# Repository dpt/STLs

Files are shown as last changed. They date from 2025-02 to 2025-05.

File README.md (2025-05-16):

OpenSCAD/STL Acorn Risc PC Components
=====================================

This repository contains OpenSCAD sources and generated STL models of the Acorn Risc PC power button and case locking pins.

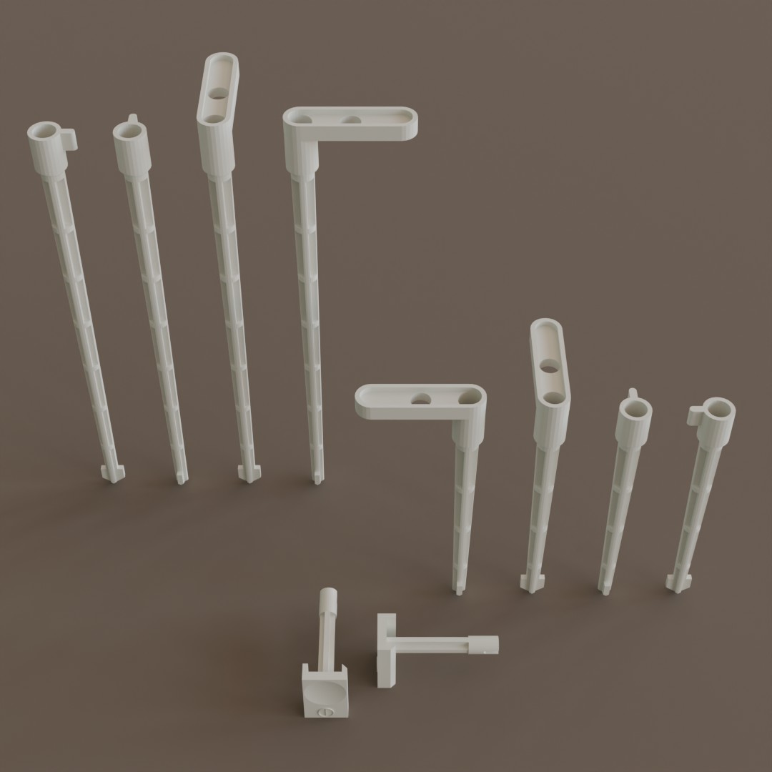
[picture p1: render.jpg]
Models


The OpenSCAD sources are provided. They're parameterised in numerous ways so you can tweak the models. e.g. you can increase the level of detail, or change the models in ways to make them amenable to your 3D printing preferences.

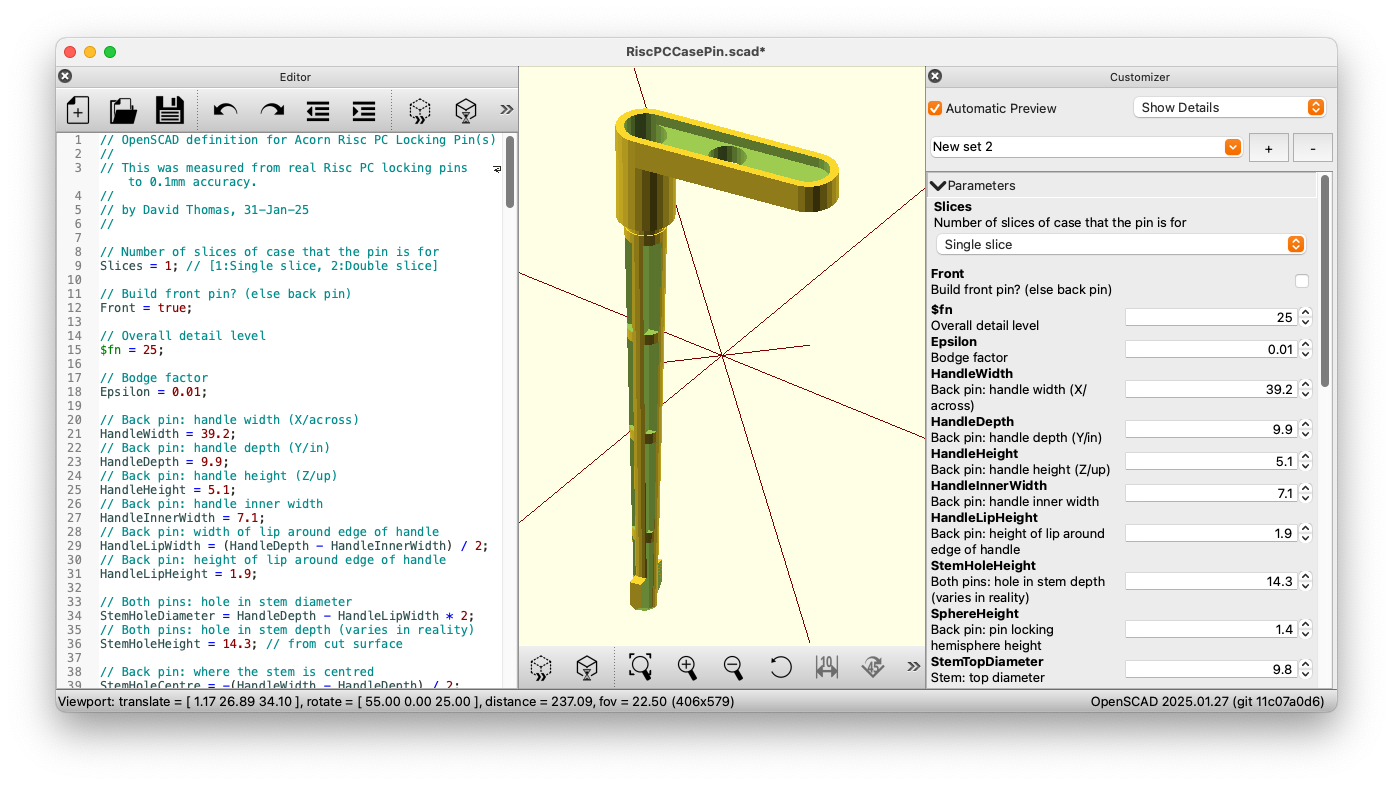
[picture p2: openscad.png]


Notes
-----
1. The parts were measured and recreated to an accuracy of 0.1mm but I can't offer any guarantees other than that.
2. The originals are injection moulded and these models are a recreation of those parts. If you 3D print these models you may need to adjust these models for your chosen method (e.g. thickening or filling in parts).
3. While you can make three slice or larger case pins note that Acorn used very sturdy metal pins in those cases.

Related Models
--------------
RiscPC Spring Insert by Nic756655 <https://www.thingiverse.com/thing:6777776>  
RiscPC Pegs 1 Slice by Nic756655 <https://www.thingiverse.com/thing:6776757>  
Archimedes & RiscPC Half-Width Podule Slot Covers by distantcamera <https://www.thingiverse.com/thing:5325053>  
Acorn RiscPC Power Switch by mcnewton <https://www.thingiverse.com/thing:2854144>

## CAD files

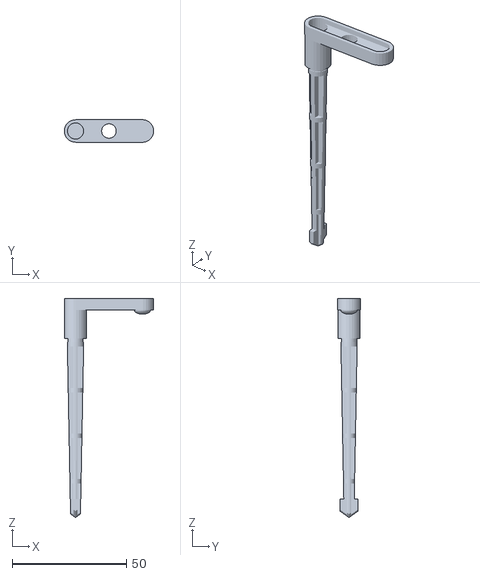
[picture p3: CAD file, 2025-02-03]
RiscPCCasePins/RiscPCCaseBackPin1L.stl
39.2 x 9.88 x 95.9

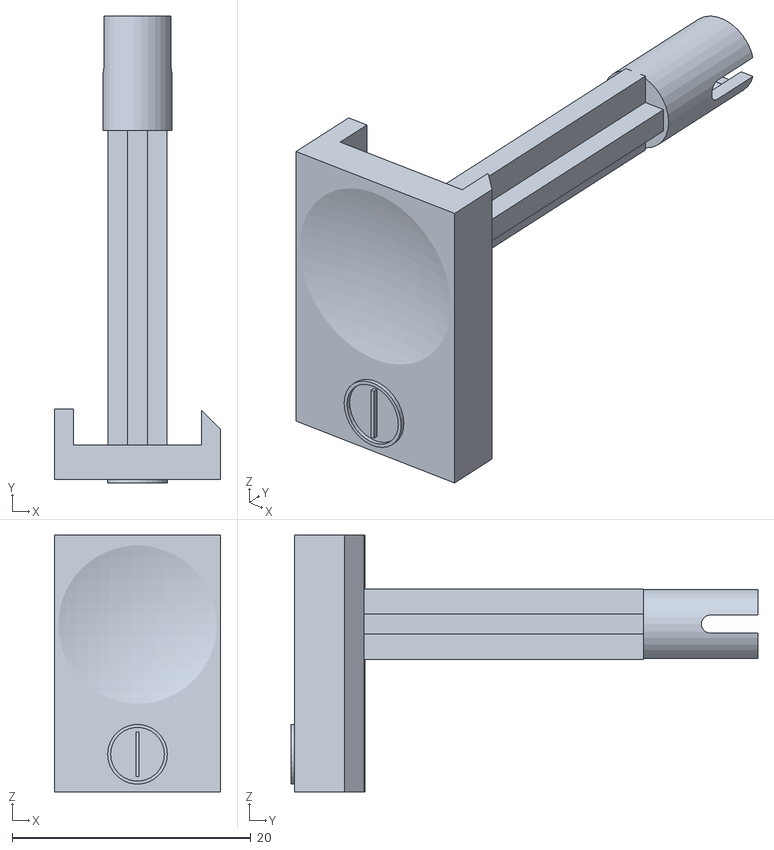
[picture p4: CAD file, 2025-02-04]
RiscPCPowerButton/RiscPCPowerButton.stl
13.9 x 39.1 x 21.5

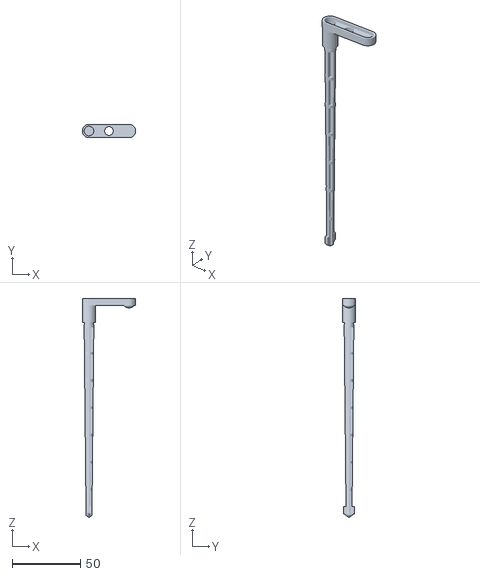
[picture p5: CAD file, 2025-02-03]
RiscPCCasePins/RiscPCCaseBackPin2L.stl
39.2 x 9.88 x 160.6

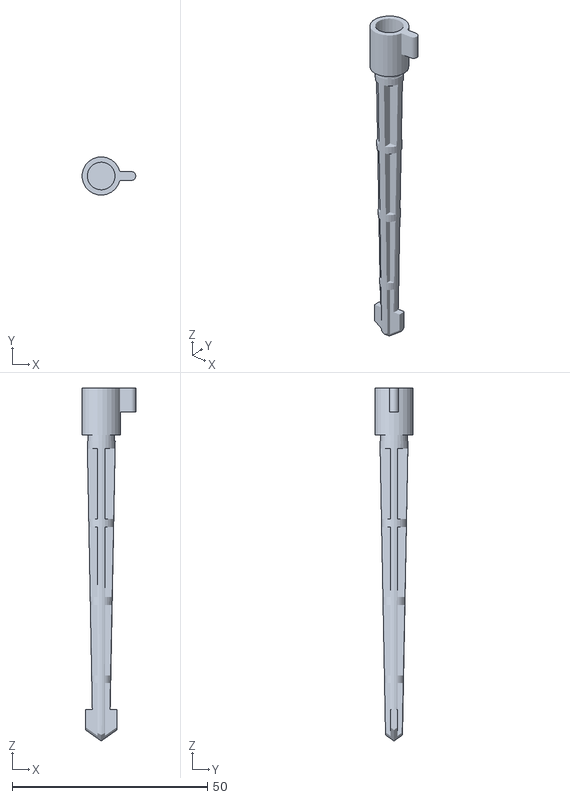
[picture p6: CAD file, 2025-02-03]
RiscPCCasePins/RiscPCCaseFrontPin1L.stl
13.7 x 9.78 x 90.3

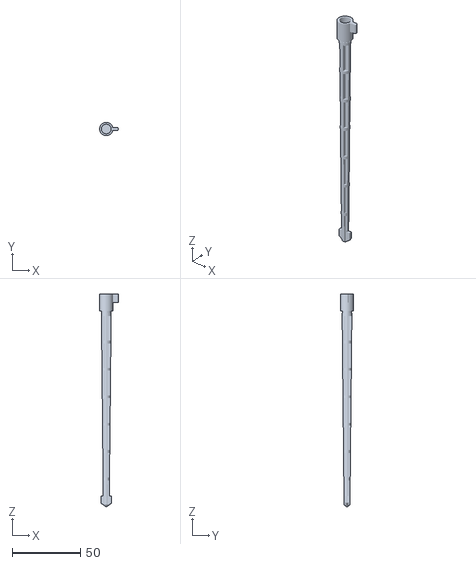
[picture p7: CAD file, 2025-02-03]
RiscPCCasePins/RiscPCCaseFrontPin2L.stl
13.7 x 9.78 x 155.5

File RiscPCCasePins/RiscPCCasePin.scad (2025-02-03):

// OpenSCAD definition for Acorn Risc PC Locking Pin(s)
//
// This was measured from real Risc PC locking pins to 0.1mm accuracy.
//
// by David Thomas, 31-Jan-25
//

// Number of slices of case that the pin is for
Slices = 1; // [1:Single slice, 2:Double slice]

// Build front pin? (else back pin)
Front = true;

// Overall detail level
$fn = 25;

// Bodge factor
Epsilon = 0.01;

// Back pin: handle width (X/across)
HandleWidth = 39.2;
// Back pin: handle depth (Y/in)
HandleDepth = 9.9;
// Back pin: handle height (Z/up)
HandleHeight = 5.1;
// Back pin: handle inner width
HandleInnerWidth = 7.1;
// Back pin: width of lip around edge of handle
HandleLipWidth = (HandleDepth - HandleInnerWidth) / 2;
// Back pin: height of lip around edge of handle
HandleLipHeight = 1.9;

// Both pins: hole in stem diameter
StemHoleDiameter = HandleDepth - HandleLipWidth * 2;
// Both pins: hole in stem depth (varies in reality)
StemHoleHeight = 14.3; // from cut surface

// Back pin: where the stem is centred
StemHoleCentre = -(HandleWidth - HandleDepth) / 2;

// Back pin: padlock hole diameter
LockHoleDiameter = HandleInnerWidth - 0.7;
// Back pin: padlock hole height
LockHoleHeight = HandleHeight + Epsilon;

// Back pin: pin locking hemisphere diameter
SphereDiameter = HandleDepth - HandleLipWidth * 2;
// Back pin: pin locking hemisphere height
SphereHeight = 1.4;

// Stem: top diameter
StemTopDiameter = 9.8;
// Stem: top depth (front single slicer is 1/2mm shorter)
StemTopHeight = (Front && Slices == 1) ? 12 : 12.5;

// Stem: O-ring inset diameter
StemORingInsetDiameter = 6.8;
// Stem: O-ring inset height
StemORingInsetHeight = 1.5;
// Stem: show the O-ring
ShowORing = false;

// Stem: fixed size portion of height
StemFixedHeight = 12.1;
// Stem: per-slice height (depth of a case slice)
StemPerSliceHeight = 64.7; // measured
// Stem: overall height (note rubber ring inset height not part of this)
StemHeight = StemFixedHeight + StemPerSliceHeight * Slices;
// Stem: diameter at top
StemUpperDiameter = 7.2;
// Stem: diameter at bottom
StemBottomDiameter = 4.3;

// Stem: cutout width/depth
StemCutoutSize = 4;
// Stem: cutout height (doesn't vary with number of slices)
StemCutoutHeight = 18;
// Stem: cutout interval
StemCutoutInterval = 20;
// Stem: increase for shallower cuts
StemCutoutOffset = 1.9;

// Barb: width
BarbWidth = 8;
// Barb: depth
BarbDepth = StemCutoutOffset;
// Barb: height
BarbHeight = 8.1;

// Front pin: width of handle (extends halfway into lip but note lip width comes from Back pin calc)
FrontHandleWidth = 14.9 - StemTopDiameter + HandleLipWidth / 2 - 2.3;
// Front pin: increase this for a chunkier handle
FrontHandleDepth = 2.3;
// Front pin: increase this for a deeper handle
FrontHandleHeight = 6.1;

module capsule(width, radius) {
	hull() {
		x = width / 2 - radius;
		translate([-x, 0, 0]) circle(r = radius);
		translate([+x, 0, 0]) circle(r = radius);
	}
}

module back_pin_top_flat() {
	difference() {
		linear_extrude(HandleHeight, center = true)
			capsule(HandleWidth, HandleDepth / 2);
			
		translate([0, 0, (HandleHeight - HandleLipHeight) / 2 + Epsilon])
			linear_extrude(HandleLipHeight, center = true)
				capsule(HandleWidth - HandleLipWidth * 2, HandleDepth / 2 - HandleLipWidth);
		
		// cut centre hole
		cylinder(h = LockHoleHeight, d = LockHoleDiameter, center = true);
	}
}

module back_pin_top() {
	difference() {
		union() {
			back_pin_top_flat();
			
			// add the top of the stem (must be here so we can cut into it)
			translate([StemHoleCentre, 0, -StemTopHeight / 2 - HandleHeight / 2])
				cylinder(h = StemTopHeight, d = StemTopDiameter, center = true);
		
			// add the spherical protrusion
			translate([-StemHoleCentre, 0, -HandleHeight / 2])
				scale([1, 1, 0.5])
					sphere(d = SphereDiameter);
		}
		
		// cut hole in top of stem
		translate([StemHoleCentre, 0, -StemHoleHeight / 2 + HandleHeight / 2 - HandleLipHeight + Epsilon * 2])
			cylinder(h = StemHoleHeight, d = StemHoleDiameter, center = true);
   }
}

module front_pin_top() {
	difference() {
		union() {
			cylinder(h = StemTopHeight, d = StemTopDiameter, center = true);
			
			translate([StemTopDiameter / 2 + FrontHandleWidth / 2 - HandleLipWidth / 2, 0, StemTopHeight / 2 - FrontHandleHeight / 2]) {
				cube([FrontHandleWidth, FrontHandleDepth, FrontHandleHeight], center = true);
				
				translate([FrontHandleWidth / 2, 0, 0])
					cylinder(h = FrontHandleHeight, d = FrontHandleDepth, center = true);
			 }
	   }
		
		translate([0, 0, 0.7 + Epsilon])
			cylinder(h = 11.2, d = StemHoleDiameter, center = true);
   }
}

module stemcutter(height) {
	dims = [StemCutoutSize, StemCutoutSize, height];
	xo = (StemCutoutSize + StemCutoutOffset) / 2;
	yo = (StemCutoutSize + StemCutoutOffset) / 2;
	for (x = [-xo, xo])
		for (y = [-yo, yo])
			translate([x, y, - height / 2])
				cube(dims, center = true);
}

module stemcuttergroup() {
	ncuts = 3.5 * Slices + 0.5;
	offset = -2;
	
	for (a = [0 : ncuts - 2])
		translate([0, 0, - StemCutoutInterval * a + offset])
			stemcutter(StemCutoutHeight);
	
	// final cut should be longer (or we get grit in the barb)
	a = floor(ncuts) - 1;
	translate([0, 0, - StemCutoutInterval * a + offset])
		stemcutter(StemCutoutHeight * 2);
}

module barbcutter() {
	// cut away diagonals
	scale(8)
		for (a = [0 : 3])
			rotate([90, 0, 90 * a + 45])
				linear_extrude(height = 2, center = true)
					polygon([[0, 0], [1, 0], [1, 1]]);
}

module stem() {
	difference() {
		union() {
			// inset for rubber o-ring
			translate([0, 0, -StemORingInsetHeight / 2]) {
				cylinder(h = StemORingInsetHeight, d = StemORingInsetDiameter, center = true);
				
				// add the o-ring itself
				if (ShowORing)
					rotate_extrude(angle = 360)
						translate([5 - 1.5 / 2, 0, 0])
							circle(d = 1.5);

				// main conic
				translate([0, 0, -StemHeight / 2 - StemORingInsetHeight / 2]) {
					cylinder(h = StemHeight, d1 = StemBottomDiameter, d2 = StemUpperDiameter, center = true);
			
					// barb (square at this point)
					translate([0, 0, -StemHeight / 2 + BarbHeight / 2])
						cube([BarbWidth, BarbDepth, BarbHeight], center = true);
				}
			}
		}

		// cut away the cuboid sections of stem
		translate([0, 0, -StemORingInsetHeight])
			stemcuttergroup();
		
		// cut the barb
		translate([0, 0, -StemORingInsetHeight - StemHeight - Epsilon])
			barbcutter();
   }
}

// Total heights as measured from my set of pins for comparison.
// Note that in reality some pins vary by 1/2mm in places.
//
// 1-slice front pin: 90.4mm (both)			-- 90.3mm under
// 2-slice front pin: 155.8mm, 155.9mm		-- 155.5mm under
//
// 1-slice back pin: 95.7mm, 96mm			-- 95.9mm in range
// 2-slice back pin: 160.6mm (17.6+143.0)	-- matches
//

union() {
	if (Front) {
		echo("Front pin total height", StemTopHeight + StemORingInsetHeight + StemHeight);

		offset = StemTopHeight / 2 + StemORingInsetHeight + StemHeight;
		translate([0, 0, offset]) {
			front_pin_top();
			translate([0, 0, -StemTopHeight / 2])
				stem();
		}
	} else {
		echo("Back pin total height", HandleHeight + StemTopHeight + StemORingInsetHeight + StemHeight);

		offset = HandleHeight / 2 + StemTopHeight + StemORingInsetHeight + StemHeight;
		translate([-StemHoleCentre, 0, offset]) {
			back_pin_top();
			translate([StemHoleCentre, 0, -HandleHeight / 2 - StemTopHeight])
				rotate([0, 0, 90])
					stem();
		}
	}
}

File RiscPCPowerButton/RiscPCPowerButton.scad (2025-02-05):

// OpenSCAD definition for an Acorn Risc PC Power Button
//
// This was measured from a real Risc PC power button to 0.1mm accuracy.
//
// by David Thomas, 28-Jan-25
//

// Note: There's another type of power button that this recreation does not
// model. It has a straight edge on its right hand back side, not sloped, and
// it has a cut in the stem. I don't have a surviving one of these buttons to
// measure.

// Overall detail level
$fn = 30;

// Bodge factor
Epsilon = 0.01;

// Width of the main button (X/across)
ButtonWidth = 13.9;
// Depth of the main button (Y/in)
ButtonDepth = 2.9;
// Height of the main button (Z/up)
ButtonHeight = 21.5;

// Width of side pieces (X)
SideWidth = 1.6;
// Depth of left side piece (Y)
LeftSideDepth = 3;
// Depth of right side piece (Y)
RightSideDepth = 2.9;

// Enable additional top fill
ExtraTopFill = false;

// Reinforce the stem by making it solid
SolidStem = false;

// Width of the stem (X)
StemWidth = 4.9;
// Depth of the stem (Y)
StemDepth = 26.3;
// Height of the stem (Z)
StemHeight = 5.9;
// Thickness of stem bars
StemMiddle = 1.7;

// Diameter of clip (X & Z)
ClipDiameter = 5.8; // 5.9 wide, 5.7 high as measured but using an average here
// Depth of clip (Y)
ClipDepth = 9.6;

// Size of square clip cut-out (X & Z)
ClipSquareCutoutSize = 3.5;
// Depth of square clip cut-out (Y)
ClipSquareCutoutDepth = 9.0;

// Width of wide clip cut-out (X)
ClipMouthWidth = 6;
// Depth of wide clip cut-out (Y)
ClipMouthDepth = 4;
// Height of wide clip cut-out (Z)
ClipMouthHeight = 1.5;

// Radius of grip bars inside mouth
ClipGripperRadius = 0.5;

// Enable power symbol on button
EnableSymbol = true;
// Diameter of symbol
SymbolDiameter = 5;
// Depth of symbol from button front
SymbolDepth = 0.3;
// Offset of symbol from button bottom
SymbolYPosition = 3.15;
// Stroke thickness of symbol
SymbolThickness = 0.25;

// Enable push impression on button
EnablePushImpression = true;
// Diameter of sphere
PushImpressionSize = 45;
// Depth of impression from button front
PushImpressionDepth = 1;
// Offset of impression from button bottom
PushImpressionYPosition = 14;

module powersymbol() {
	linear_extrude(SymbolDepth)
		union() {
			difference() {
				circle(d = SymbolDiameter);
				circle(d = SymbolDiameter - SymbolThickness * 2);
			}
			square([SymbolThickness, SymbolDiameter * 3 / 4], center = true);
		}
}

module plainfront() {
	union() {
		// front
		button = [ButtonWidth, ButtonDepth, ButtonHeight];
		cube(size = button);

		lefthand = [SideWidth, LeftSideDepth, ButtonHeight];
		translate([0, ButtonDepth, 0])
			cube(size = lefthand);

		righthand = [SideWidth, RightSideDepth, ButtonHeight];
		translate([ButtonWidth - SideWidth, ButtonDepth, 0])
			difference() {
				cube(size = righthand);

				// using Epsilon here to avoid edges colliding
				t = SideWidth;
				translate([0, RightSideDepth - t, -Epsilon])
					linear_extrude(ButtonHeight + Epsilon * 2)
						polygon(points=[[t + Epsilon, -Epsilon],
								[t + Epsilon, t + Epsilon],
								[-Epsilon, t + Epsilon]]);
			}
		
		// top fill (additional)
		if (ExtraTopFill) {
			top = [ButtonWidth - SideWidth * 2, LeftSideDepth, SideWidth];
			translate([SideWidth, ButtonDepth, ButtonHeight - SideWidth])
				cube(size = top);
		}
	}
}

module adornedfront() {
	union() {
		difference() {
			plainfront();
			
			// push impression
			if (EnablePushImpression) {
				translate([ButtonWidth / 2, -PushImpressionSize / 2 + PushImpressionDepth, PushImpressionYPosition])
					sphere(d = PushImpressionSize, $fn = $fn * 5);
			}
		}

		// power symbol
		if (EnableSymbol) {
			translate([ButtonWidth / 2, -SymbolDepth, SymbolYPosition])
				rotate([-90, 0, 0])
					powersymbol();
		}
	}
}

module stem() {
	if (!SolidStem) {
		union() {
			// cross part
			linear_extrude(StemDepth)
				union() {
					square([StemMiddle, StemHeight], center = true);
					square([StemWidth, StemMiddle], center = true);
				}

			// clip part
			translate([0, 0, StemDepth + ClipDepth / 2])
				cylinder(h = ClipDepth, r = ClipDiameter / 2, center = true);
		}
	} else {
		translate([0, 0, (StemDepth + ClipDepth) / 2])
			cylinder(h = StemDepth + ClipDepth, r1 = ClipDiameter / 2, r2 = ClipDiameter / 2, center = true);
	}
}

module clipcutter() {
	difference() {
		union() {
			// cut out the square section
			translate([0, 0, (ClipDepth - ClipSquareCutoutDepth) / 2 + Epsilon])
				cube([ClipSquareCutoutSize, ClipSquareCutoutSize, ClipSquareCutoutDepth], center = true);

			// cut out the mouth section
			translate([0, 0, (ClipDepth - ClipMouthDepth) / 2 + Epsilon]) {
				cube([ClipMouthWidth, ClipMouthHeight, ClipMouthDepth], center = true);
				
				// round off the mouth section
				translate([0, 0, -ClipMouthDepth / 2])
					rotate([0, 90, 0])
						cylinder(h = ClipMouthWidth, r = 0.75, center = true);
			}
		}
		
		// add grip bars inside the mouth
		
		y = ClipSquareCutoutSize / 2 + ClipGripperRadius / 2;
		
		translate([0, y, ClipSquareCutoutDepth / 2 - 1])
			rotate([0, 90, 0])
				cylinder(h = ClipSquareCutoutSize, r = ClipGripperRadius, center = true);
		
		translate([0, -y, ClipSquareCutoutDepth / 2 - 1])
			rotate([0, 90, 0])
				cylinder(h = ClipSquareCutoutSize, r = ClipGripperRadius, center = true);
	}
}

module cutstem() {
	difference() {
		stem();
		
		translate([0, 0, StemDepth + ClipDepth / 2])
			clipcutter();
	}
}

union() {
	adornedfront();
	
	translate([ButtonWidth / 2, ButtonDepth, 17 - StemHeight / 2])
		rotate([-90, 0, 0])
			cutstem();
}

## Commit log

2025-01-28 Add Risc PC front power button
    [RiscPCPowerButton.scad, RiscPCPowerButton.stl]
2025-01-28 Round off the mouth corner
    [RiscPCPowerButton.scad, RiscPCPowerButton.stl]
2025-01-28 Allow for a featureless button
    [RiscPCPowerButton.scad]
2025-01-28 Allow for additional top fill
    This will make the button look more solid from the top but makes it harder to prise off.
    [RiscPCPowerButton.scad]
2025-01-28 Allow for reinforced stem
    [RiscPCPowerButton.scad]
2025-01-28 Add comments and reindent
    [RiscPCPowerButton.scad]
2025-01-28 Make power symbol more scalable
    [RiscPCPowerButton.scad]
2025-01-28 Fix reinforced stem detail level
    [RiscPCPowerButton.scad]
2025-01-28 Update STL
    [RiscPCPowerButton.stl]
2025-01-28 Add screenshot
    [RiscPCPowerButton.scad, RiscPCPowerButton.stl]
2025-01-30 Add grippy bars inside the mouth
    [RiscPCPowerButton.scad, RiscPCPowerButton.stl]
2025-01-31 First stab at a rear locking pin
    [RiscPCCasePin.scad, RiscPCCasePin.stl]
2025-01-31 Fix barb cut failure
    [RiscPCCasePin.scad, RiscPCCasePin.stl]
2025-02-01 More accurate (but more to do)
    [RiscPCCasePin.scad]
2025-02-01 RiscPCCasePin: Fix missing stem cutter at bottom
    [RiscPCCasePin.scad]
2025-02-01 RiscPCPowerButton: Use $fn for overall detail level
    [RiscPCPowerButton.scad]
2025-02-01 RiscPCCasePin: Add front pin
    [RiscPCCaseBackPin1L.stl, RiscPCCaseBackPin2L.stl, RiscPCCaseFrontPin1L.stl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]
2025-02-01 Remove old STL
    [RiscPCCasePin.stl]
2025-02-02 RiscPCCasePin: Shift pins into correct final positions
    - variety of fettling
    - longer cut for final stem cut
    - also improve configuration docs
    - removed unneeded vars
    - use binary for STLs
    [RiscPCCaseBackPin1L.stl, RiscPCCaseBackPin2L.stl, RiscPCCaseFrontPin1L.stl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]
2025-02-03 RiscPCCasePin: Fettling
    - use StemTopHeight=12 for front+single slice pins only, otherwise 12.5
    - increase StemRingInsetDiameter from 6.7 to 6.8
    - decrease StemRingInsetHeight from 1.9 to 1.5
    - increase StemFixedHeight from 12 to 12.1
    - decrease StemPerSliceHeight from 65 to 64.7 (matching case slice)
    - increase StemUpperDiameter from 7.1 to 7.2
    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
    [RiscPCCaseBackPin1L.stl, RiscPCCaseBackPin2L.stl, RiscPCCaseFrontPin1L.stl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]
2025-02-04 RiscPCPowerButton: Rename and document configuration values
    [RiscPCPowerButton.scad, RiscPCPowerButton.stl]
2025-02-05 RiscPCPowerButton: Sync
    [RiscPCPowerButton.scad]
2025-02-05 RiscPCPowerButton: Add a note about a variant
    [RiscPCPowerButton.scad]
